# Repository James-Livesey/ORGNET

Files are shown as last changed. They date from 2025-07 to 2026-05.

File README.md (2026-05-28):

# ORGNET
A wireless networking peripheral for the Psion Organiser II, in a datapack form factor.

## Getting the code
This repository contains Git submodules that must be cloned to be able to assemble the ORGNET application's code and emulate the Organiser II's firmware. To clone this repository, run:

```bash
git clone --recurse-submodules https://github.com/James-Livesey/ORGNET
```

## Building and running
To build ORGNET's firmware and application, run:

```bash
./build.sh
```

Running this script without any arguments will also upload the firmware and application build to the RP2350 over USB.

To test ORGNET's application in an emulator, run:

```bash
pushd app; ./build.sh --test; popd
```

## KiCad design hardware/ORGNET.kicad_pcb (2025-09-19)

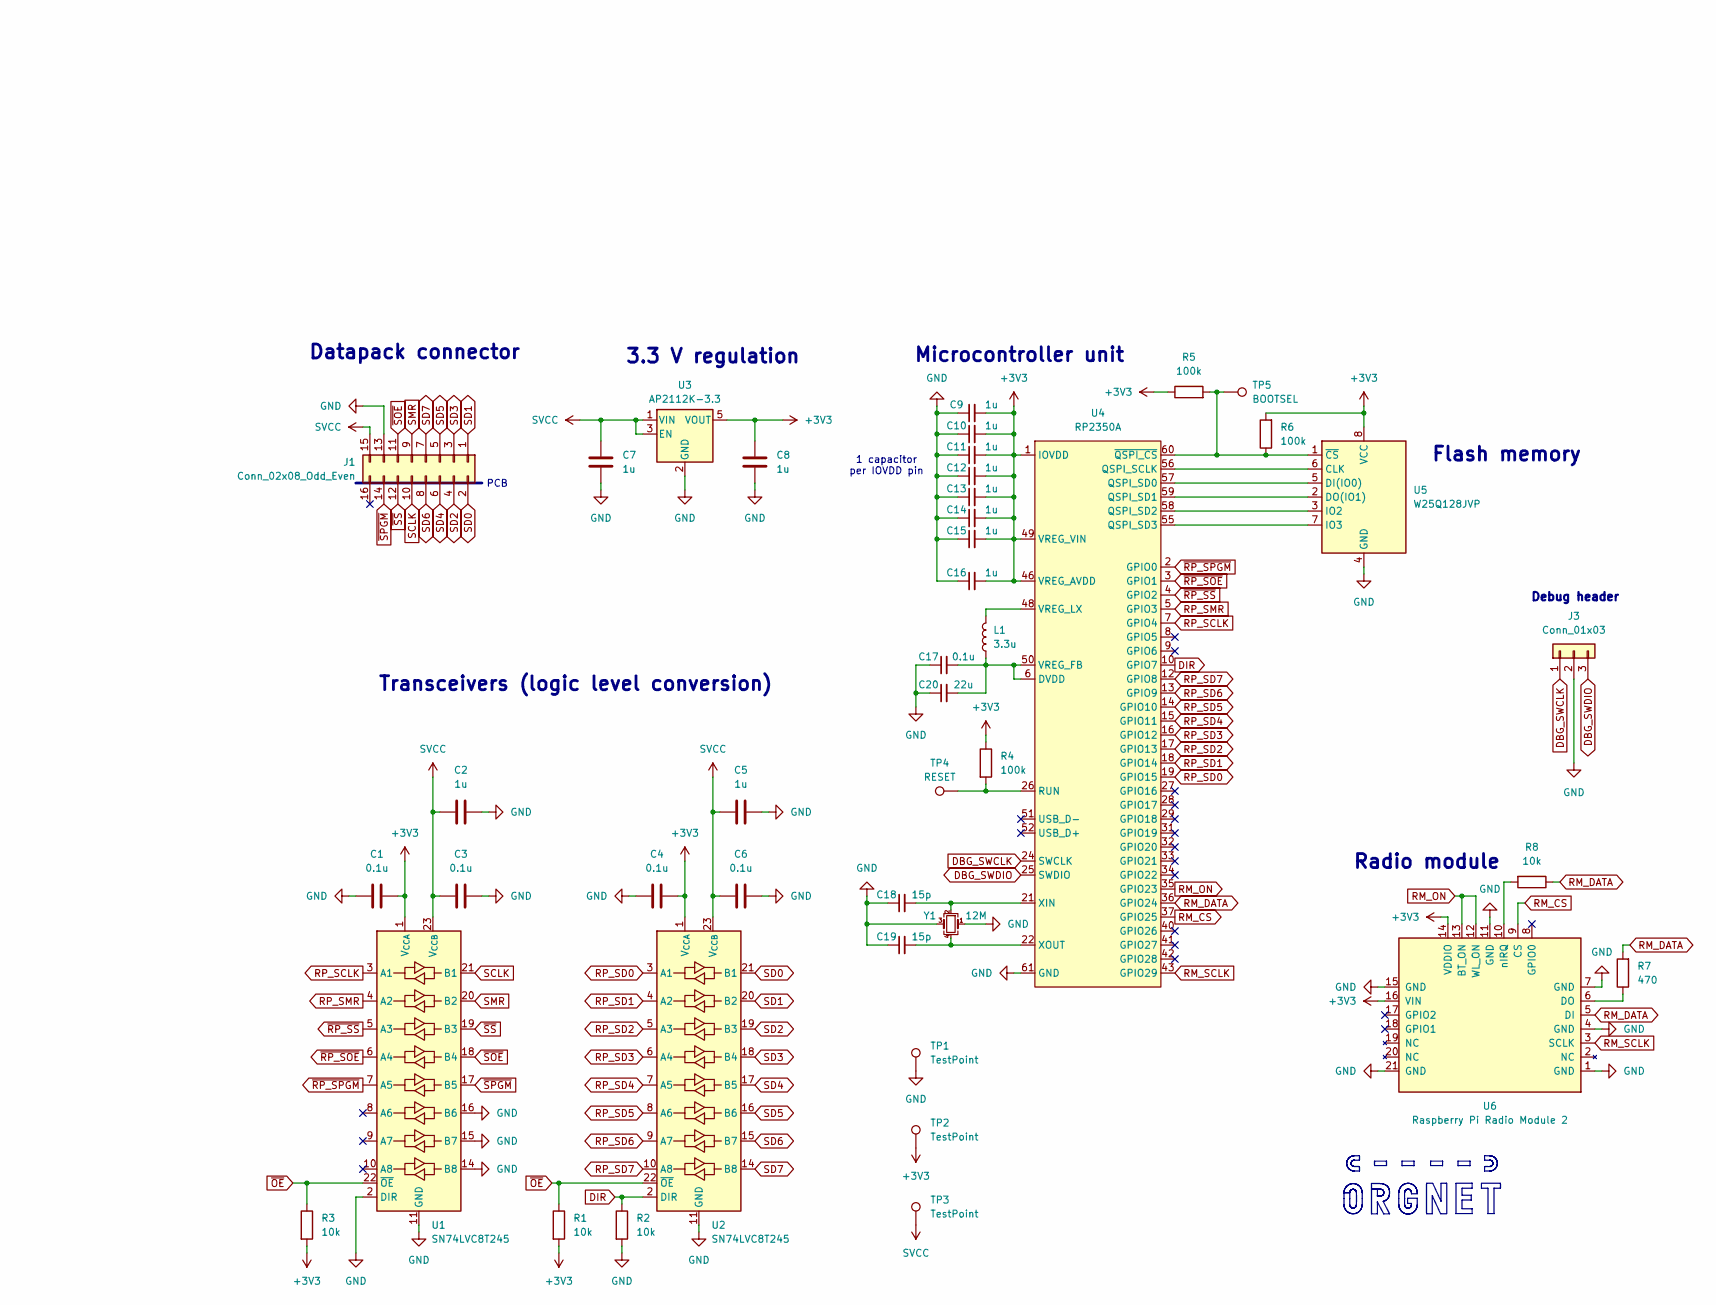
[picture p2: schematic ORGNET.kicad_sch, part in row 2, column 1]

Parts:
C1, C3, C4, C6, C17: 0.1u; C_0402_1005Metric_Pad0.74x0.62mm_HandSolder
C2, C5, C7, C8, C9, C10, C11, C12, C13, C14, C15, C16: 1u; C_0402_1005Metric_Pad0.74x0.62mm_HandSolder
C18, C19: 15p; C_0402_1005Metric_Pad0.74x0.62mm_HandSolder
C20: 22u; C_0402_1005Metric_Pad0.74x0.62mm_HandSolder
J1: Conn_02x08_Odd_Even; PinSocket_2x08_P2.54mm_Horizontal
J3: Conn_01x03; JST_SH_BM03B-SRSS-TB_1x03-1MP_P1.00mm_Vertical
L1: 3.3u; L_1210_3225Metric_Pad1.42x2.65mm_HandSolder
R1, R2, R3, R8: 10k; R_0402_1005Metric_Pad0.72x0.64mm_HandSolder
R4, R5, R6: 100k; R_0402_1005Metric_Pad0.72x0.64mm_HandSolder
R7: 470; R_0402_1005Metric_Pad0.72x0.64mm_HandSolder
TP1, TP2, TP3: TestPoint; TestPoint_Pad_D2.0mm
TP4: RESET; TestPoint_Pad_D2.0mm
TP5: BOOTSEL; TestPoint_Pad_D2.0mm
U1, U2: SN74LVC8T245; TSSOP-24_4.4x7.8mm_P0.65mm
U3: AP2112K-3.3; SOT-23-5
U4: RP2350A; QFN-60-1EP_7x7mm_P0.4mm_EP3.4x3.4mm
U5: W25Q128JVP; WSON-8-1EP_6x5mm_P1.27mm_EP3.4x4.3mm
U6: Raspberry Pi Radio Module 2; rpi_rmc20452t
Y1: 12M; Crystal_SMD_Abracon_ABM8G-4Pin_3.2x2.5mm

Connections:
+3V3: C1.1, C4.1, C8.1, C9.2, C10.2, C11.2, C12.2, C13.2, C14.2, C15.2, C16.2, R1.2, R3.2, R4.1, R5.1, R6.2, TP2.1, U1.1 (V_{CCA}), U2.1 (V_{CCA}), U3.5 (VOUT), U4.1 (IOVDD), U4.11 (IOVDD), U4.20 (IOVDD), U4.30 (IOVDD), U4.38 (IOVDD), U4.44 (IOVDD), U4.45 (IOVDD), U4.46 (VREG_AVDD), U4.49 (VREG_VIN), U4.53 (IOVDD), U4.54 (IOVDD), U5.8 (VCC), U6.14 (VDDIO), U6.16 (VIN)
DBG_SWCLK: J3.1, U4.24 (SWCLK)
DBG_SWDIO: J3.3, U4.25 (SWDIO)
DIR: R2.1, U2.2 (DIR), U4.10 (GPIO7)
GND: C1.2, C2.1, C3.1, C4.2, C5.1, C6.1, C7.2, C8.2, C9.1, C10.1, C11.1, C12.1, C13.1, C14.1, C15.1, C16.1, C17.1, C18.1, C19.1, C20.1, J1.13, J3.2, R2.2, TP1.1, U1.2 (DIR), U1.11 (GND), U1.12 (GND), U1.13 (GND), U1.14 (B8), U1.15 (B7), U1.16 (B6), U2.11 (GND), U2.12 (GND), U2.13 (GND), U3.2 (GND), U4.47 (GND), U4.61 (GND), U5.4 (GND), U6.1 (GND), U6.4 (GND), U6.7 (GND), U6.11 (GND), U6.15 (GND), U6.21 (GND), Y1.1, Y1.3
unnamed: U4.56 (QSPI_SCLK), U5.6 (CLK)
unnamed: U4.57 (QSPI_SD0), U5.5 (DI(IO0))
unnamed: U4.59 (QSPI_SD1), U5.2 (DO(IO1))
unnamed: U4.58 (QSPI_SD2), U5.3 (IO2)
unnamed: U4.55 (QSPI_SD3), U5.7 (IO3)
unnamed: R4.2, TP4.1, U4.26 (RUN)
unnamed: C17.2, C20.2, L1.1, U4.6 (DVDD), U4.23 (DVDD), U4.39 (DVDD), U4.50 (VREG_FB)
unnamed: L1.2, U4.48 (VREG_LX)
unnamed: C18.2, U4.21 (XIN), Y1.2
unnamed: C19.2, U4.22 (XOUT), Y1.4
unnamed: R5.2, R6.1, TP5.1, U4.60 (~QSPI_CS), U5.1 (~CS)
unnamed: R7.1, U6.6 (DO)
unnamed: R8.2, U6.10 (nIRQ)
RM_CS: U4.37 (GPIO25), U6.9 (CS)
RM_DATA: R7.2, R8.1, U4.36 (GPIO24), U6.5 (DI)
RM_ON: U4.35 (GPIO23), U6.12 (WL_ON), U6.13 (BT_ON)
RM_SCLK: U4.43 (GPIO29), U6.3 (SCLK)
RP_SCLK: U1.3 (A1), U4.7 (GPIO4)
RP_SD0: U2.3 (A1), U4.19 (GPIO15)
RP_SD1: U2.4 (A2), U4.18 (GPIO14)
RP_SD2: U2.5 (A3), U4.17 (GPIO13)
RP_SD3: U2.6 (A4), U4.16 (GPIO12)
RP_SD4: U2.7 (A5), U4.15 (GPIO11)
RP_SD5: U2.8 (A6), U4.14 (GPIO10)
RP_SD6: U2.9 (A7), U4.13 (GPIO9)
RP_SD7: U2.10 (A8), U4.12 (GPIO8)
RP_SMR: U1.4 (A2), U4.5 (GPIO3)
SCLK: J1.10, U1.21 (B1)
SD0: J1.2, U2.21 (B1)
SD1: J1.1, U2.20 (B2)
SD2: J1.4, U2.19 (B3)
SD3: J1.3, U2.18 (B4)
SD4: J1.6, U2.17 (B5)
SD5: J1.5, U2.16 (B6)
SD6: J1.8, U2.15 (B7)
SD7: J1.7, U2.14 (B8)
SMR: J1.9, U1.20 (B2)
SVCC: C2.2, C3.2, C5.2, C6.2, C7.1, J1.15, TP3.1, U1.23 (V_{CCB}), U1.24 (V_{CCB}), U2.23 (V_{CCB}), U2.24 (V_{CCB}), U3.1 (VIN), U3.3 (EN)
~OE: R1.1, R3.1, U1.22 (~OE), U2.22 (~OE)
~RP_SOE: U1.6 (A4), U4.3 (GPIO1)
~RP_SPGM: U1.7 (A5), U4.2 (GPIO0)
~RP_SS: U1.5 (A3), U4.4 (GPIO2)
~SOE: J1.11, U1.18 (B4)
~SPGM: J1.14, U1.17 (B5)
~SS: J1.12, U1.19 (B3)

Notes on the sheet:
Flash memory
Microcontroller unit
PCB
Debug header
3.3 V regulation
1 capacitor per IOVDD pin
Datapack connector
Transceivers (logic level conversion)
Radio module

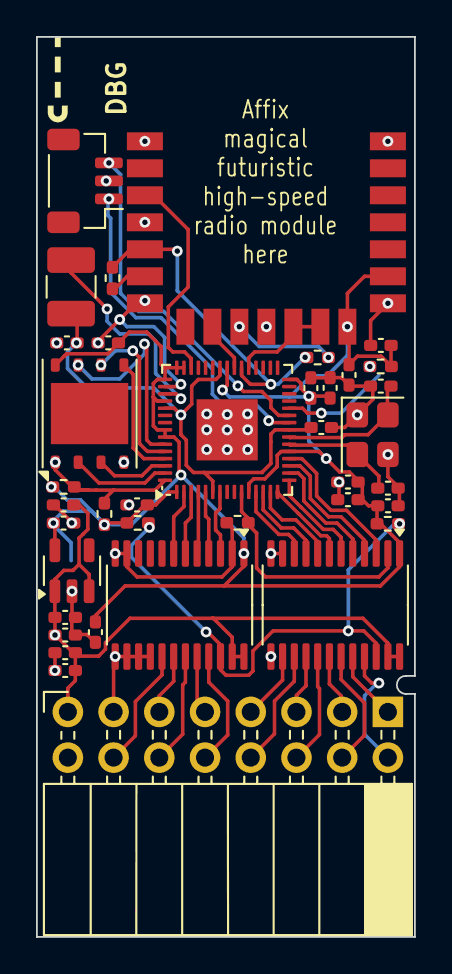
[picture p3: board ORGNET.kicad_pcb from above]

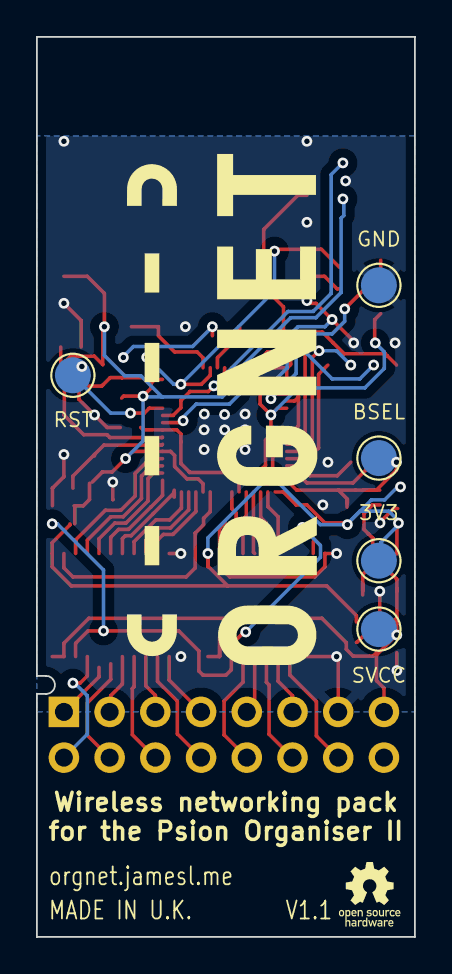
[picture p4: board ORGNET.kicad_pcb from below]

Board: 2 copper layers, 21.0 x 50.0 mm, 43 parts (5 on the bottom side), 50 nets.

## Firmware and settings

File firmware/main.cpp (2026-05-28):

#include <stdio.h>
#include "pico/stdlib.h"
#include "pico/multicore.h"
#include "hardware/clocks.h"
#include "hardware/vreg.h"

#include "datapack.h"
#include "cmd.h"
#include "wifi.h"
#include "_service.h"

#define WIFI_SCAN_INTERVAL 3000

Datapack* datapack;
uint64_t lastWifiScan = 0;

void stepper() {
    while (true) {
        Datapack::the()->step();
    }
}

int main() {
    stdio_init_all();

    datapack = Datapack::the();

    datapack->loadCode((char*)serviceCode + 6, serviceCode_len - 6); // Truncating 6 bytes to remove OPK header

    vreg_set_voltage(VREG_VOLTAGE_1_30);
    set_sys_clock_khz(250'000, true);
    // irq_set_mask_enabled(0x0F, false);
    multicore_launch_core1(stepper);

    lastWifiScan = time_us_64();

    while (true) {
        if (datapack->hasAvailableCommand()) {
            sleep_ms(10);

            CommsBuffer buffer = datapack->getCommsBuffer();

            cmd::processCommand(&buffer);
            datapack->setCommsBuffer(&buffer);
        }

        if (time_us_64() - lastWifiScan > WIFI_SCAN_INTERVAL * 1000) {
            wifi::scan();

            lastWifiScan = time_us_64();
        }

        tight_loop_contents();
    }

    return 0;
}

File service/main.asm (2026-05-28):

.INCLUDE MOSVARS.INC
.INCLUDE MOSHEAD.INC
.INCLUDE MSWI.INC

.ORG $241B-31

head:
	.ASCII	"ORG"
	.WORD	%prgend-%xx
	.BYTE	$FF

xx:
	.BYTE	$6C		; Bootable; paged; RAM-based
	.BYTE	$04		; Size 32K
	.BYTE	$00		; Code only
	.BYTE	$41		; Device number
	.BYTE	$10		; Version 1.0
	.BYTE	$41		; Priority
	.WORD	%root-%xx	; Device overlay address
	.WORD	$FFFF		; Checksum
	.BYTE	$09
	.BYTE	$81
	.ASCII	"MAIN    "
	.BYTE	$90
	.BYTE	$02
	.BYTE	$80
	.WORD	%prgend-%root	; Size of code

.OVER root

start:
	.WORD	$0000
	.BYTE	$00
	.BYTE	$41		; Device number
	.BYTE	$10		; Version 1.0
	.BYTE	(endvec-vec)/2	; Number of vectors

vec:
	.WORD	install
	.WORD	remove
	.WORD	language
	.WORD	error_show_vec
	.WORD	comms_begin
	.WORD	comms_read_vec
	.WORD	comms_read_byte
	.WORD	comms_write_vec
	.WORD	comms_wait
	.WORD	udg_vec
	.WORD	line_begin_vec
	.WORD	line_show
	.WORD	line_noscrlx
endvec:

install:
	jsr	comms_init
	bcs	install_ret	; Return error if comms could not init

	ldaa	kbb_pkof	; Prevent auto pack switch-off
	staa	old_kbb_pkof
	ldaa	#0
	staa	kbb_pkof

	jsr	logo_show	; Show ORGNET logo

	jsr	apps_add_tl	; Add ORGNET apps to top-level menu

	os	kb$getk		; Wait for keypress

	clc			; Return success signal

install_ret:
	rts

remove:
	ldaa	#$0C		; Clear screen
	os	dp$emit

	ldab	remove_msg	; Print remove message to screen
	ldx	#remove_msg+1
	os	dp$prnt

	jsr	apps_rm_tl	; Remove ORGNET apps from top-level menu

	ldaa	old_kbb_pkof	; Restore auto pack switch-off behaviour
	staa	kbb_pkof

	os	kb$getk		; Wait for keypress

	clc			; Return success signal
	rts

remove_msg:
	.ASCIC	"Remove vector"

language:
	sec			; Return not-handled signal
	rts

old_kbb_pkof:
	.BYTE 0

.INCLUDE vectors.inc
.INCLUDE error.inc
.INCLUDE comms.inc
.INCLUDE apps.inc
.INCLUDE appldr.inc
.INCLUDE udg.inc
.INCLUDE logo.inc
.INCLUDE tlmenu.inc
.INCLUDE line.inc

.EOVER

.INCLUDE netcfg.inc

.OVER prgend
.EOVER

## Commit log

2025-07-17 Create basic schematic for hardware
    [ORGNET.kicad_pcb, ORGNET.kicad_sch]
2025-07-18 Add expansion and debug headers
    [ORGNET.kicad_pcb, ORGNET.kicad_sch]
2025-07-19 Begin laying out footprints on PCB
    [ORGNET.kicad_pcb, ORGNET.kicad_sch]
2025-07-21 Start routing PCB
    [ORGNET.kicad_pcb, ORGNET.kicad_sch]
2025-07-21 Finish off PCB routing
    [ORGNET.kicad_pcb]
2025-07-22 Fix order of pins on connector
    [ORGNET.kicad_pcb, ORGNET.kicad_sch]
2025-07-22 Add logo and branding to PCB
    [ORGNET.kicad_pcb]
2025-07-22 Add branding to schematics
    [ORGNET.kicad_pcb, ORGNET.kicad_sch]
2025-07-22 Fix logo colour on schematic
    [ORGNET.kicad_sch]
2025-07-23 Make a few minor changes to PCB layout and silkscreen
    [ORGNET.kicad_pcb, ORGNET.kicad_sch]
2025-07-23 Implement a few more minor PCB tweaks
    [ORGNET.kicad_pcb, ORGNET.kicad_sch]
2025-07-23 Remove unused ground plane vias
    [ORGNET.kicad_pcb]
2025-07-26 Add Gerber files
    [ORGNET-B_Cu.gbr, ORGNET-B_Mask.gbr, ORGNET-B_Paste.gbr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]
2025-07-26 Add notch and use 0406 resistors/capacitors
    [ORGNET-B_Cu.gbr, ORGNET-B_Mask.gbr, ORGNET-B_Paste.gbr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]
2025-07-29 Make minor fixes to PCB layout
    [ORGNET.kicad_pcb]
2025-09-03 Update schematic to fix MCU overheating
    [ORGNET.kicad_sch]
2025-09-17 Add basic assembly code to include in firmware
2025-09-18 Fix indentation in assembly files
2025-09-18 Prevent pack auto switch-off when ORGNET is in use
    [main.asm]
2025-09-19 Fix power routing to address short circuiting issue
    [ORGNET.kicad_pcb, ORGNET.kicad_sch]
2025-12-10 Add option to prevent horizontal scrolling in line renderer
    [main.asm]
2025-12-11 Return current scroll position values from `line_show` subroutine
2025-12-17 Implement basic Wi-Fi listing commands on Pi Pico side
2025-12-18 Add Wi-Fi scanning on Pi Pico side (WIP)
2026-05-28 Fix app code references
    [main.cpp]
2026-05-28 Fix comms error and try making Wi-Fi more reliable
    [main.cpp]
